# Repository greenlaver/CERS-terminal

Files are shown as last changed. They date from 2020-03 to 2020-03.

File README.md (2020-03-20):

# CERS-terminal

[CERS-terminal](https://github.com/greenlaver/CERS-terminal) is the terminal device developed for [CERS(COVID-19 Entrance Recording System)](https://github.com/Yukiho-YOSHIEDA/CERS).

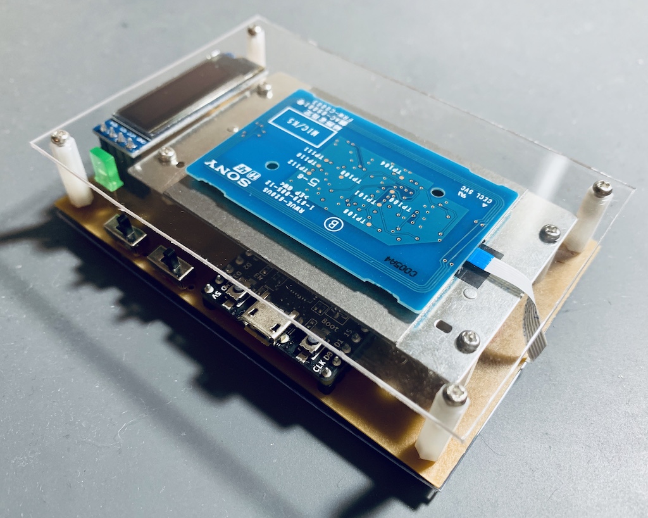
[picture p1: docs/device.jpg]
device


## Device Design

Schematic and board design files are contained in [KiCad](KiCad).

## Dependencies

Works on ESP32, developed with [Arduino IDE](https://www.arduino.cc/en/main/software).

- [ArduinoHkNfcRw](lib/ArduinoHkNfcRw) : RC-S620S Customized Arduino R/W library
- [U8g2](https://github.com/olikraus/u8g2) : 2.27.6
- [ArduinoJson](https://github.com/bblanchon/ArduinoJson) : 6.14.0

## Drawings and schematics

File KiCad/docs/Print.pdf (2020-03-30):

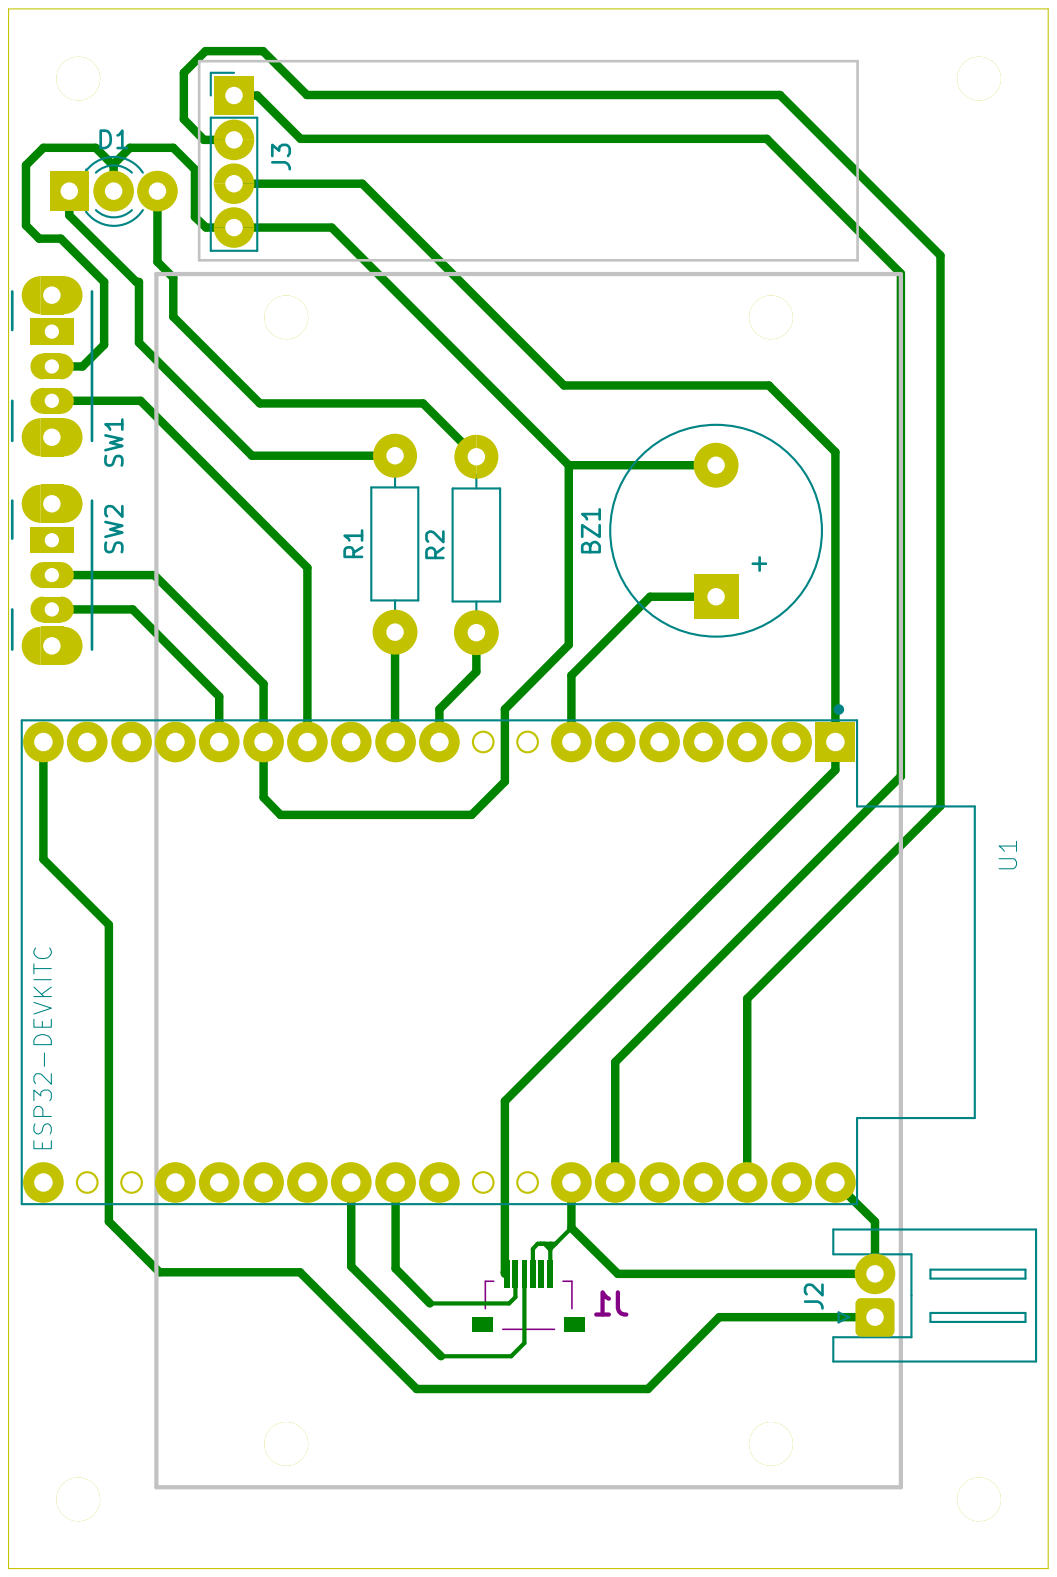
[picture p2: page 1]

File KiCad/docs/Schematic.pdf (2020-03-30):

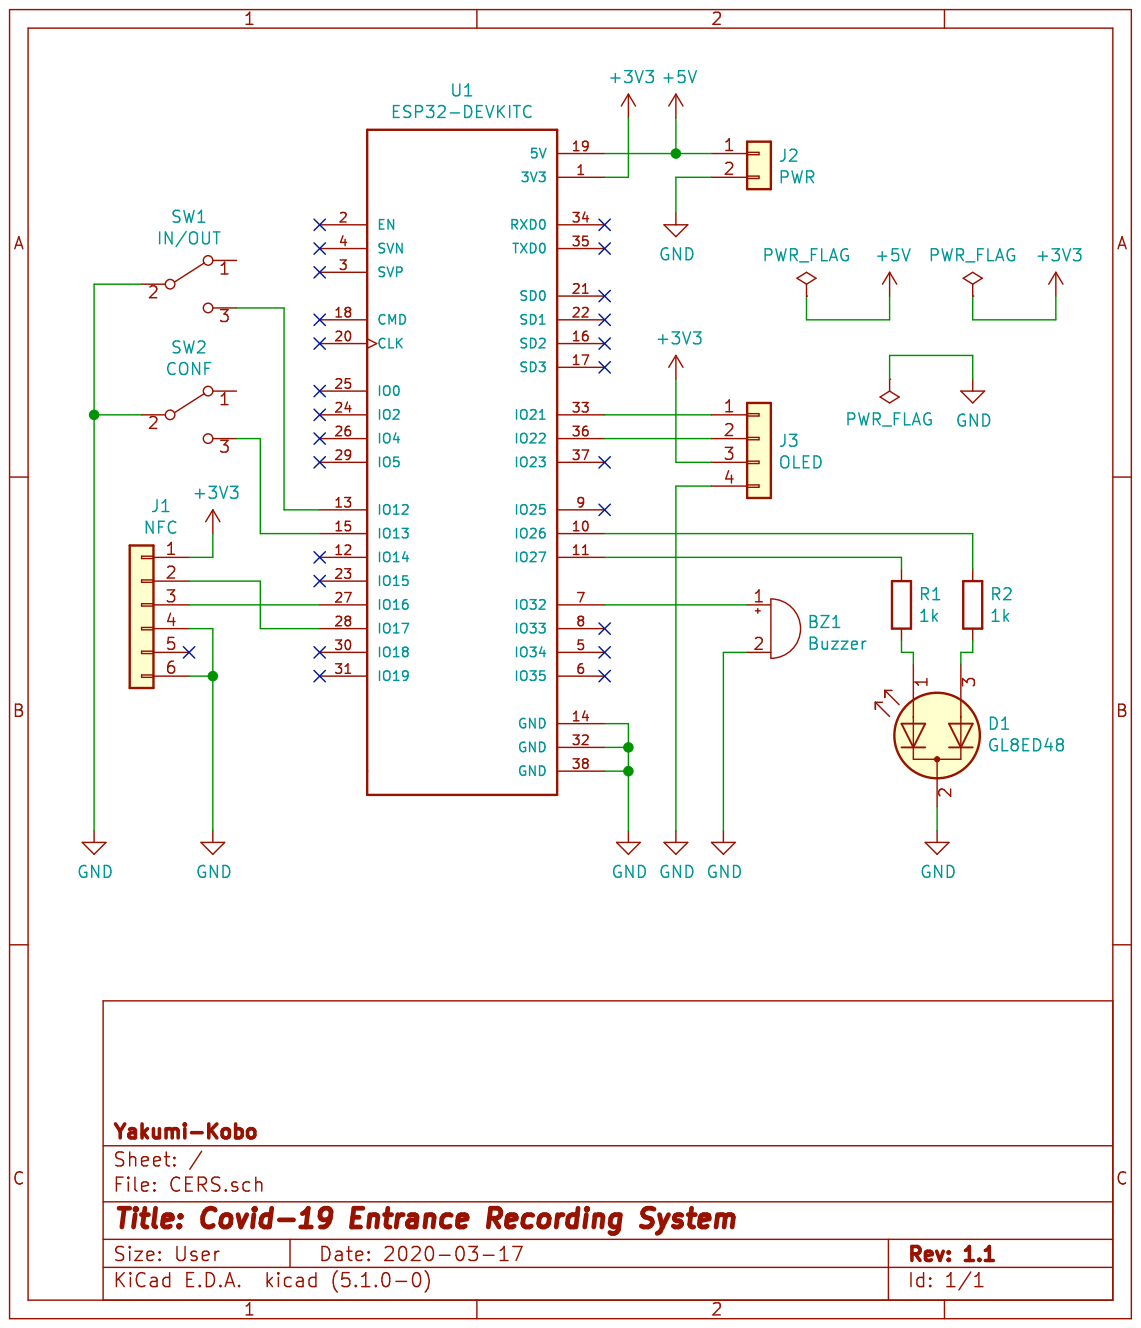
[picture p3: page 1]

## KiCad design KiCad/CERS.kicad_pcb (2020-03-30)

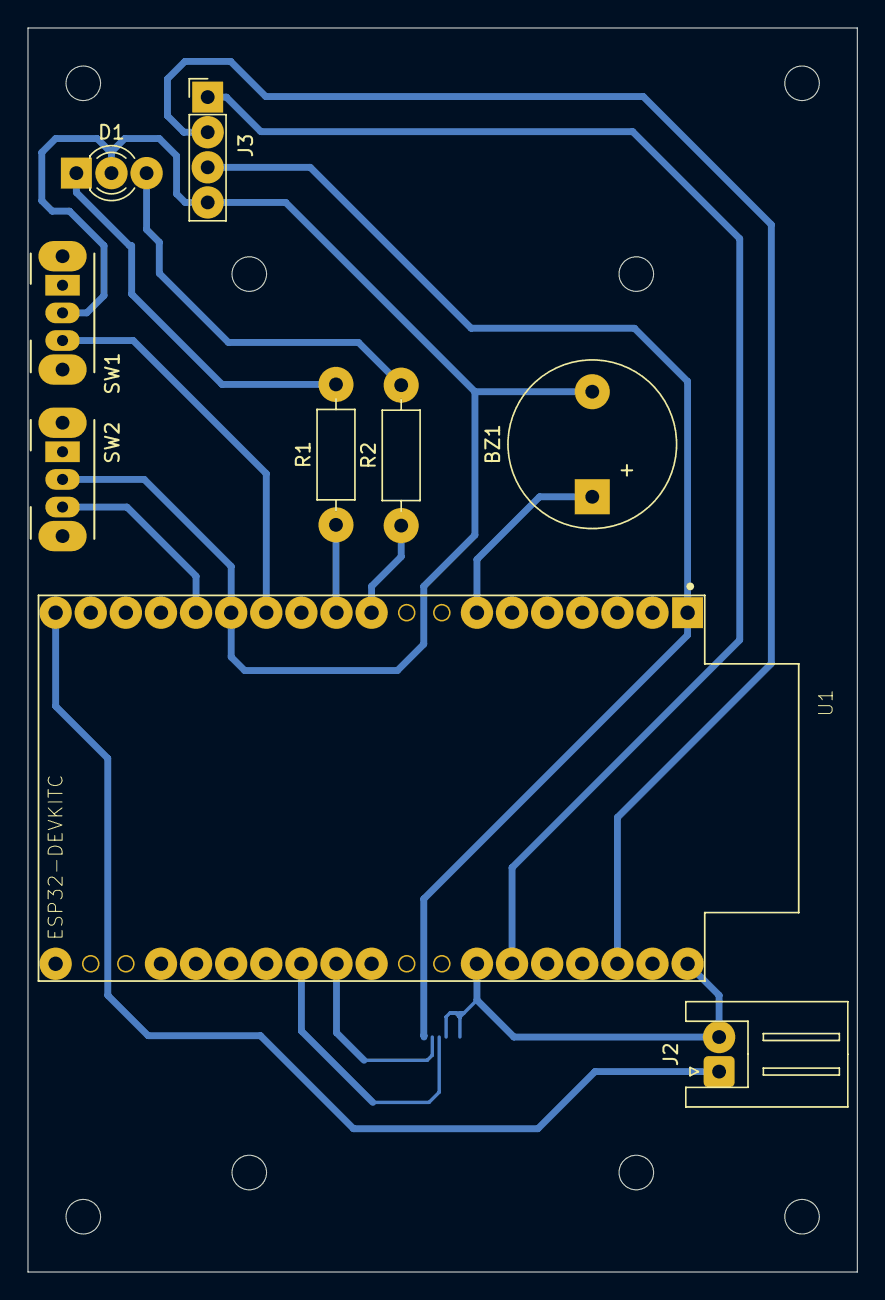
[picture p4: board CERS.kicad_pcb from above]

Board: 2 copper layers, 60.0 x 90.0 mm, 10 parts (1 on the bottom side), 14 nets.

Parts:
BZ1: Buzzer; Buzzer_12x9.5RM7.6
D1: GL8ED48; LED_D3.0mm-3
J1: NFC; 23287026
J2: PWR; JST_XH_S2B-XH-A_1x02_P2.50mm_Horizontal
J3: OLED; PinHeader_1x04_P2.54mm_Vertical
R1, R2: 1k; R_Axial_DIN0207_L6.3mm_D2.5mm_P10.16mm_Horizontal
SW1: IN/OUT; SW_CuK_OS102011MA1QN1_SPDT_Angled
SW2: CONF; SW_CuK_OS102011MA1QN1_SPDT_Angled
U1: ESP32-DEVKITC; XCVR_ESP32-DEVKITC

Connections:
+3V3: J1.1, J3.3, U1.1
+5V: J2.1, U1.19
GND: BZ1.2, D1.2, J1.4, J1.6, J2.2, J3.4, SW1.2, SW2.2, U1.14, U1.32, U1.38
unnamed: BZ1.1, U1.7
unnamed: D1.1, R1.2
unnamed: D1.3, R2.2
unnamed: J1.2, U1.28
unnamed: J1.3, U1.27
unnamed: J3.1, U1.33
unnamed: J3.2, U1.36
unnamed: R1.1, U1.11
unnamed: R2.1, U1.10
unnamed: SW1.3, U1.13
unnamed: SW2.3, U1.15

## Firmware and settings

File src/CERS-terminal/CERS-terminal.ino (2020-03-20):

#include "GpioManager.h"
#include "NFCReader.h"
#include "NetworkManager.h"
#include "DisplayManager.h"
#include <U8g2lib.h>
#include <Wire.h>

// OLED Library
U8G2_SSD1306_128X32_UNIVISION_1_HW_I2C oled(U8G2_R0, U8X8_PIN_NONE);

/// =======================================
///  UART Settings
/// =======================================
// Connected to PC via USB-Serial converter
#define UART0_BAUD 115200
// Connected to RC-S620/S NFC sensor
//        RX:IO16  TX:IO17
#define UART2_BAUD 115200

GpioManager gpioMan;
NFCReader nfcReader;
NetworkManager netMan;
DisplayManager dispMan;

char localtime_str[30];

void setup()
{
  Serial.begin(UART0_BAUD);
  Serial2.begin(UART2_BAUD);

  gpioMan.GpioInit();
  dispMan.DisplayInit(&oled, &gpioMan);
  nfcReader.NFCInit(&gpioMan, &dispMan);
  netMan.NetworkInit(&gpioMan, &dispMan);

  Serial.println("COVID-19 NFC Program.");
  dispMan.DrawSplashScreen("1.0.0");
  gpioMan.setLEDColor(GpioManager::Color::GREEN, 0);

  // Conf Mode Check
  if (gpioMan.isConfMode())
  {
    netMan.enterConfigMode();
  }

  // Connect to Wifi
  netMan.connectWifi();
  netMan.setupNTP();
}

void loop()
{
  // Conf Mode Check
  if (gpioMan.isConfMode())
  {
    netMan.enterConfigMode();
  }

  // NTP
  if (!netMan.getNTPTime(localtime_str, 30))
    showNTPError();

  // New Arriving Card Process
  if (nfcReader.readCard())
  {
    gpioMan.setLEDColor(GpioManager::Color::GREEN, 50);

    netMan.post(gpioMan.isInMode(),
                nfcReader.student_info,
                localtime_str);

    gpioMan.setLEDColor(GpioManager::Color::GREEN, 0);
    delay(1000);
  }

  // Display
  dispMan.DrawWaitCard(localtime_str);

  // Wifi Health Check
  if (WiFi.status() != WL_CONNECTED)
  {
    showWifiError();
    netMan.connectWifi();
  }
}

void showNTPError()
{
  Serial.println("=== NTP FAILED. ===");
  dispMan.DrawNTPError();
  gpioMan.ringBuzzer(2000);
}

void showWifiError()
{
  Serial.println("=== Wifi Discon. ===");
  dispMan.DrawWifiError();
  gpioMan.ringBuzzer(2000);
}

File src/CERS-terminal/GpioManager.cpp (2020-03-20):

#include "GpioManager.h"

void GpioManager::GpioInit()
{
  // Switch
  pinMode(SW_MODE, INPUT_PULLUP);
  pinMode(SW_CONF, INPUT_PULLUP);

  // LED
  pinMode(LED_GRN, OUTPUT);
  digitalWrite(LED_GRN, LOW);
  pinMode(LED_RED, OUTPUT);
  digitalWrite(LED_RED, LOW);

  // Buzzer
  pinMode(BUZ_PIN, OUTPUT);
  digitalWrite(BUZ_PIN, LOW);

  // Reset color
  setLEDColor(Color::None, 0);
}

void GpioManager::setLEDColor(Color color, uint32_t pace_ms)
{
  current_color = color;
  ledBlinker.detach();

  digitalWrite(LED_GRN, color & 1);
  digitalWrite(LED_RED, (color >> 1) & 1);

  if (pace_ms > 0)
  {
    ledBlinker.attach_ms(pace_ms, blinkLED, (uint8_t)current_color);
  }
}

bool GpioManager::isInMode()
{
  return digitalRead(SW_MODE);
}

bool GpioManager::isConfMode()
{
  return !digitalRead(SW_CONF);
}

void GpioManager::buzzerOn()
{
  digitalWrite(BUZ_PIN, HIGH);
}

void GpioManager::buzzerOff()
{
  digitalWrite(BUZ_PIN, LOW);
}

void GpioManager::ringBuzzer(uint32_t bz_time)
{
  buzzerOn();
  delay(bz_time);
  buzzerOff();
}

void blinkLED(uint8_t color)
{
  if (color & 1)
    digitalWrite(LED_GRN, !digitalRead(LED_GRN));
  if ((color >> 1) & 1)
    digitalWrite(LED_RED, !digitalRead(LED_RED));
}

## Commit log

2020-03-18 Add KiCad files.
    [CERS.kicad_pcb, CERS.sch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]
2020-03-18 Add ESP32 firmware.
2020-03-18 Add LED Blinking System using Ticker.
2020-03-19 Fix name-encoding, Add Conf-Mode.
    [CERS-terminal.ino, DisplayManager.cpp, GpioManager.cpp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]
2020-03-20 Fix switch configure mode.
    [GpioManager.cpp]
2020-03-20 Fix R1 value.
    [CERS.kicad_pcb, CERS.sch]
2020-03-30 Update KiCad files rev. 1.1
    [CERS.kicad_pcb, CERS.sch]
